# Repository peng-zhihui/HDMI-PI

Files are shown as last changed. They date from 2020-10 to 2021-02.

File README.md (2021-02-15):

> 这是我最近设计的一个HDMI转MIPI模块，可以用于驱动各种手机屏幕当显示器用。

## 有什么用？

大家知道现在的手机屏幕素质非常高，且价格低廉（毕竟有智能手机的普及量撑腰，作为维修配件买的话非常便宜），相比于绝大多数桌面显示器拥有十分无敌的分辨率、像素密度、可视角、色彩还原甚至刷新率。

大家又知道，我对于小巧精致的电子产品有执着的追求，可市面上几乎找不到用手机屏幕做的迷你显示器，所以本项目就是为了解决这个需求。至于迷你HDMI显示器有什么用，电视盒子、单反相机、树莓派之类的开发板都带HDMI接口，**即插即用随身携带的高分屏它不香吗？**

## 硬件原理

目前绝大多数的手机屏幕和小型高分辨率高刷新率屏幕基本都是MIPI接口，相比于RGB、LVDS、SPI等接口MIPI是一个非常强大的高速接口，它分为CSI和DSI两个规格（没错就是树莓派上预留的那个DSI），可以根据带宽需求自由配置lane数，且每个lane传输速率超过1Gbps。

而HDMI是最为常用的视频接口，几乎所有视频输出设备都会带一个HDMI接口。

**因此我们需要的就是一个HDMI转MIPI的硬件模块。**要实现这个目的可以有几种方案，走FPGA或者用ASIC芯片。

用FPGA的方案这里有个老哥开源了：https://hackaday.io/project/364-mipi-dsi-display-shieldhdmi-adapter

他用Spartan-6 FPGA成功驱动了iPhone4的屏幕并接受HDMI的信号输入，感兴趣的可以参考。

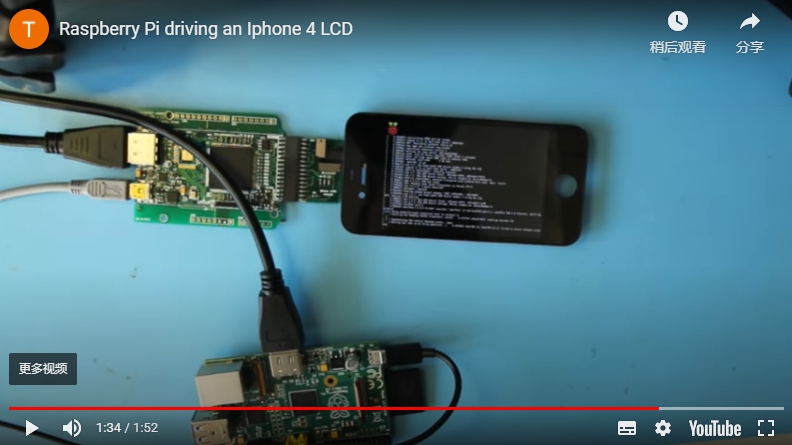
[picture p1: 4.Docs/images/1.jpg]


因为我对FPGA不是很熟，所以我采用ASIC专用IC的方案来设计。

#### 东芝方案

东芝有一款TC358870XBG芯片，支持2x4lane的屏幕驱动，输入源是HDMI，这是目前在AR眼镜中比较流行的一个方案，该芯片非常强大，但是缺点是资料极其稀缺。**我花了很长时间搞到了原厂的datasheet和相关文档，仓库里面都共享出来了。**

根据原厂的评估板我也设计了一个测试模块，电路已经开源在仓库。

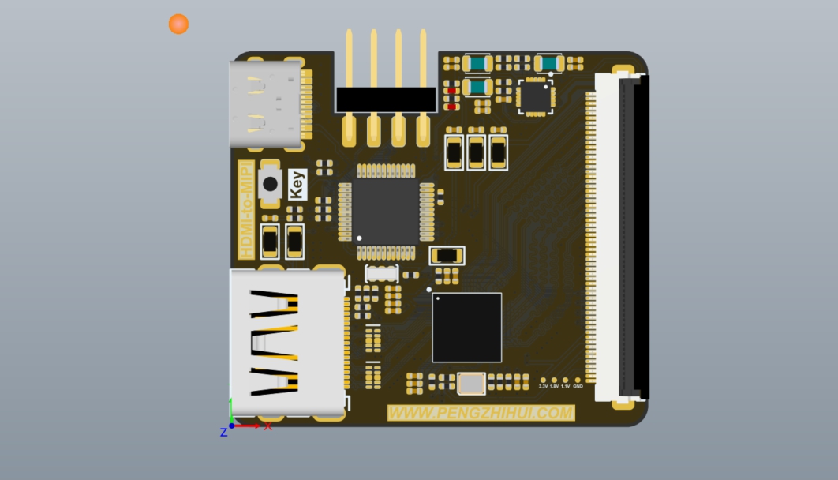
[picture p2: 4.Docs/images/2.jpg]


这个方案的软件我还没有写，感兴趣的同学可以参考文档做后续开发，**也欢迎有进展的同学提交代码到仓库~**

> 目前东芝方案的固件代码已经由[ylj2000](https://github.com/ylj2000)基本实现了，其源码已经整合到本仓库，感谢[ylj2000](https://github.com/ylj2000)同学的开源代码~
>
> 大家可以去他的仓库具体了解：
>
> [ylj2000/HDMI_To_MIPI: A Hdmi to Mipi conversion module based on Toshiba TC358870 (github.com)](https://github.com/ylj2000/HDMI_To_MIPI)

#### 龙讯方案

国产还有一个龙讯方案LT6911，与上面的方案相比龙讯性能上稍弱一些，但是该芯片内置了一个51核的MCU，所以可以直接在片上编程（东芝的需要额外加一个单片机用I2C配置芯片）。

该方案的优点就是成本相对较低，芯片外围电路也更简洁，缺点是，**资料比东芝的还少...**

厂家不开放软硬资料，连datasheet都没有，所以几乎无法个人开发。**但是**，万能的野生钢铁侠通过一些特殊手段，还是跟代理商拿到了一些资料，包括部分源码（核心lib封装好了我拿不到，只有上层API）。但是因为签了NDA保密协议，源码部分我不好分享出来，除了源码其他部分我都开源了，而大家DIY的话也不需要源码，我可以提供预编译的固件供大家下载，所以这个方案适合给直接复制项目的同学参考。

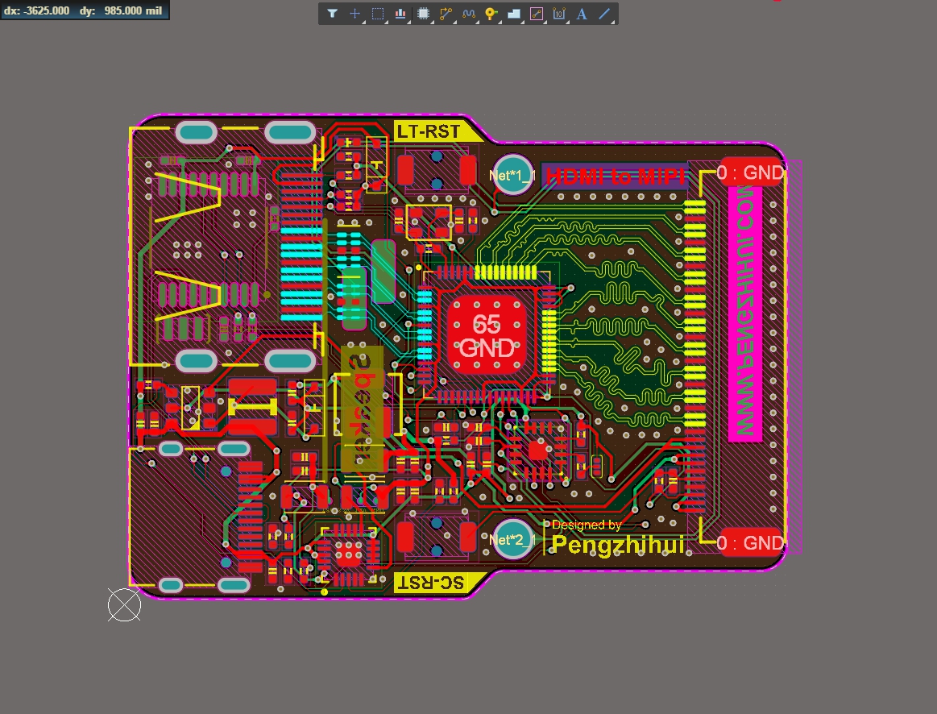
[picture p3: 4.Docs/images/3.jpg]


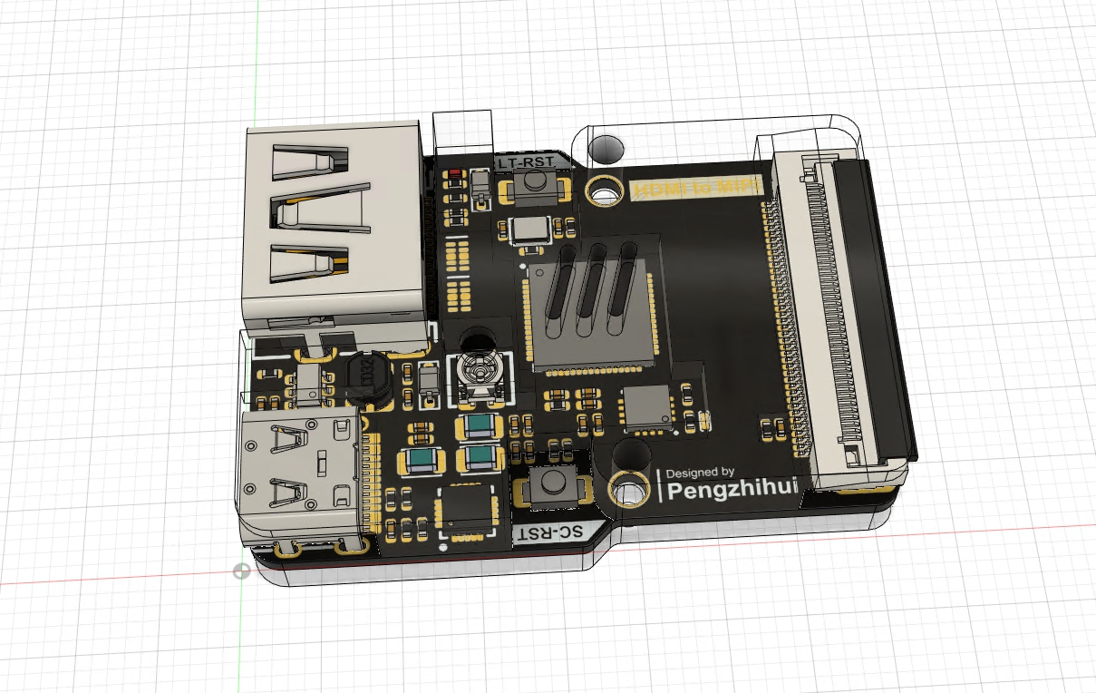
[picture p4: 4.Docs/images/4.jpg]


最终驱动的效果如下，以5.5寸的屏幕为例：

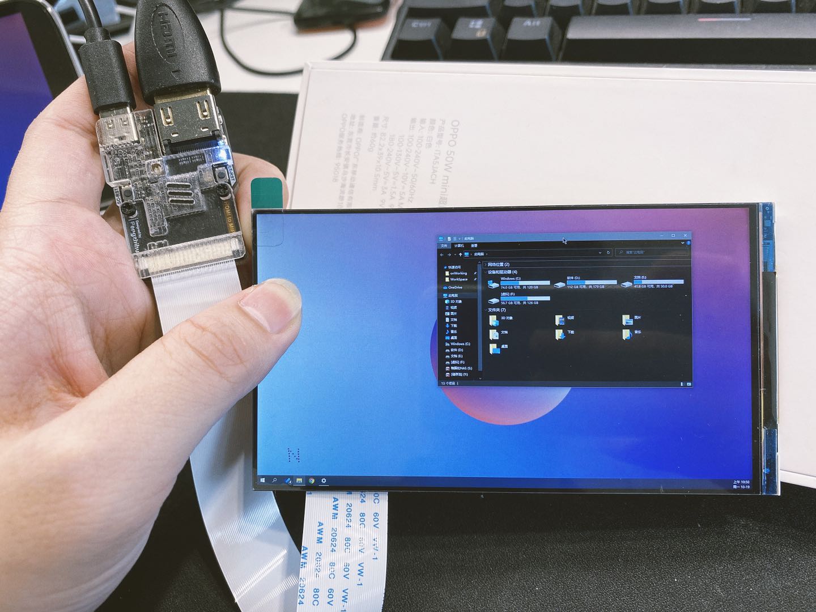
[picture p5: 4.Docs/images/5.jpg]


## 总结

我后面还会继续用这个模块尝试驱动更多屏幕，有开发能力的同学可以在我给出的东芝方案的基础上继续开发，这个方案的自由度会高很多，我后面有空也会继续完成这个方案的:D

#### 找资料和开发不易，记得给仓库点星星哈~~

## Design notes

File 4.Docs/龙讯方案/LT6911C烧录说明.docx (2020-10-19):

1、LT6911x使用IIC去进行烧录，必须使用USB转IIC工具

淘宝上搜索“CH341T模块 USB转12C”，就能找到这个模块。

2、安装好USB转IIC工具及驱动后，在设备管理器里面就有这个设备，驱动可以找淘宝店主提供

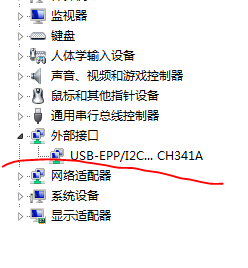
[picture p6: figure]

3、根据IIC总线的”SDA”,”SCL”,”GND”线序连接好开发板与模块，给模块上电（3.3V）

4、打开烧录工具“LT1605_I2C2SPI_V2_100k.exe”（从LT1605_download_tool.rar里面解压出来），选择好烧录码，点击“烧写”，等待烧录成功。

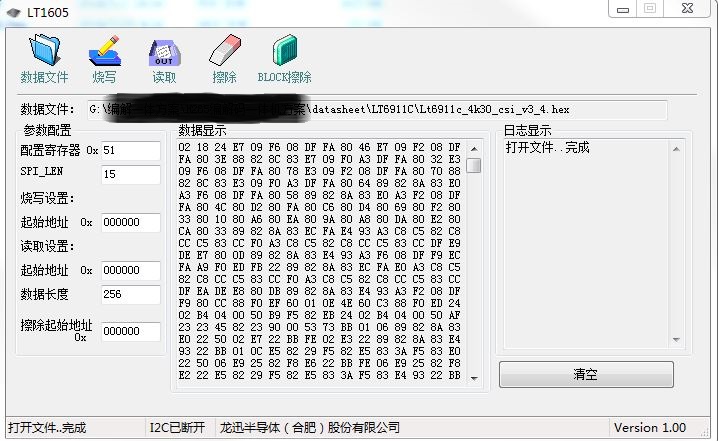
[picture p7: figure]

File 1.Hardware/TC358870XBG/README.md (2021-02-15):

## 文件说明

* MiniDisplay：这是我原版设计电路，硬件已经验证过但是固件代码还没来得及写
* Converter-10.1：和上面的核心板配套的10.1寸屏转接板
* MiniDisplay-ylj2000：这是由[ylj2000](https://github.com/ylj2000)基于我原版硬件方案修改的电路，将转接板改为了排针连接的形式，另外这个方案的固件代码也已经由[ylj2000](https://github.com/ylj2000)实现，目前适配了5.5寸的1080p屏幕
* Converter_5_5：和上面的板子配套的转接板

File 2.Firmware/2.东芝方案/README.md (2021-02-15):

#### By [ylj2000](https://github.com/ylj2000)

# 关于硬件和软件

>这个项目的硬件部分参考了稚晖的原理图，PCB部分由于原版的板厂做出来价格太高，所以进行了重画，是一块核心板加一块转接板的方式。这里两块板之间的连接是用的排针，虽然对这种高速信号来说不太好，但是实际测试是可以使用的。屏幕使用的是稚晖POCKET-LCD开源项目中的那块屏幕，开源链接：https://github.com/peng-zhihui/PocketLCD。
>由于龙迅方案的资料等都不太好弄到，所以这个项目做的是东芝方案，目前已经点亮了这块屏幕，之后也会尽量找时间点亮其他屏幕。由于MIPI屏幕的特性，必须针对每一块屏幕定制驱动。这个项目会开源点亮屏幕的源码，目前还没有写状态切换方面的代码，只能先插上HDMI之后再插上电源才能显示，如果拔下HDMI就需要重新上电。由于原版的原理图中iic接口没加上拉电阻，我这里也没有注意到，所以在调试的时候需要外接iic的上拉。

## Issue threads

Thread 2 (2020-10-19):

有没有考虑出售成品方案呢，新手不会弄啊

fanxinghaoyue0, 2020-10-19:

ice-shimmer, 2020-10-19:
或者能不能教我们怎么用这些资料在淘宝上定做

fanxinghaoyue0, 2020-10-19:
> 或者能不能教我们怎么用这些资料在淘宝上定做

哈哈你这个太伸手党了

ice-shimmer, 2020-10-19:
> > 或者能不能教我们怎么用这些资料在淘宝上定做
>
> 哈哈你这个太伸手党了

啊这。。说的怪不好意思的，但是真的是没有啥基础啊

Leadrive, 2020-10-19:
我也没基础，点个星支持下。

lizhaoguosina, 2020-10-19:
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

先下载下来，然后用AD打开，导出成打板工厂要求的文件在线下单打板就好了。等板子回来然后对应的焊接应该就好了。只是我实在不确定哪家的芯片可以胜任这项任务😂

Professor-Chen, 2020-11-29:
有成品，大家一起拼pocket-lcd   qq群：719019471

willshion, 2020-11-30:
其它屏幕捏？ 小米？？？
做不做 摄像头驱动？？？
为环保 点star

Professor-Chen, 2020-11-30:
其他屏幕没有驱动暂时做不了
不做

------------------&nbsp;原始邮件&nbsp;------------------
发件人:                                                                                                                        "peng-zhihui/HDMI-PI"                                                                                    <notifications@github.com&gt;;
发送时间:&nbsp;2020年12月1日(星期二) 凌晨0:50
收件人:&nbsp;"peng-zhihui/HDMI-PI"<HDMI-PI@noreply.github.com&gt;;
抄送:&nbsp;"1224288756"<1224288756@qq.com&gt;;"Comment"<comment@noreply.github.com&gt;;
主题:&nbsp;Re: [peng-zhihui/HDMI-PI] 有没有考虑出售成品方案呢，新手不会弄啊 (#2)

其它屏幕捏？ 小米？？？
 做不做 摄像头驱动？？？
 为环保 点star

—
You are receiving this because you commented.
Reply to this email directly, view it on GitHub, or unsubscribe.

materliu, 2021-02-24:
同求成品，愿意掏钱买

rcHoper, 2021-02-24:
TB有现货的，300rmb左右

materliu, 2021-02-24:
> TB有现货的，300rmb左右

关键字是啥啊

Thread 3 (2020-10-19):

求屏幕型号

Libunko, 2020-10-19:
README手上拿的那块屏幕是什么型号啊，夏普的吗？

Libunko, 2020-10-20:
[屏库网](https://www.panelook.cn/sizmodlist_cn.php?st=E27&pl=&sizes[]=550&signal_type_category=140&st=E27&by=asc&production_state=-1&best=0) 可以按条件搜索屏幕面板

Closed 2020-10-20.

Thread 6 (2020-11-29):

关于屏幕、DSI和树莓派

nineandthreequarters, 2020-11-29:
> 树莓派有 **_DSI_** +手机屏幕用 **_DSI_**  ==> 树莓派可以直接连手机拆机屏幕进行显示
>- [ ] **这条假设成立吗？**

tansirui, 2020-11-29:
应该不可以直接用，单单接口就得转接。

12101111, 2020-11-29:
https://github.com/anholt/linux/wiki/VC4-display-support
https://github.com/anholt/linux/wiki/Raspberry-Pi-and-other-MIPI-DSI-display-panels
https://www.cnblogs.com/B1ue/p/10334900.html

Closed 2020-11-29.

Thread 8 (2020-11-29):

关于所支持的屏幕分辨率

JYH851, 2020-11-29:
在固件中我看到那个固件的标题中写的是800*1280，我想知道是这个固件只能支持这个分辨率吗

peng-zhihui, 2020-11-29:
不只是分辨率，驱动屏幕的核心是对接屏幕控制器，每一块屏幕都不一样的，需要针对特定屏幕修改固件（虽然同一型号的控制器修改量很小）

发自我的iPhone

------------------ 原始邮件 ------------------
发件人: JYH851 <notifications@github.com&gt;
发送时间: 2020年11月29日 17:29
收件人: peng-zhihui/HDMI-PI <HDMI-PI@noreply.github.com&gt;
抄送: Subscribed <subscribed@noreply.github.com&gt;
主题: 回复：[peng-zhihui/HDMI-PI] 关于所支持的屏幕分辨率 (#8)

在固件中我看到那个固件的标题中写的是800*1280，我想知道是这个固件只能支持这个分辨率吗

—
You are receiving this because you are subscribed to this thread.
Reply to this email directly, view it on GitHub, or unsubscribe.

0x01x0, 2020-11-29:
有个报废iPad屏幕 能不能上？

Closed 2020-11-29.

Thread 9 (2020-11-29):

关于转接板

tansirui, 2020-11-29:
你好，请问一下仓库里是不是没有阿美林5.5寸的转接板？如果自己画的差分线要怎么处理？

hexesdesu, 2020-11-30:
把pocketlcd里面的转接部分抠出来用(￣o￣) . z Z

tansirui, 2020-12-01:
> 把pocketlcd里面的转接部分抠出来用(￣o￣) . z Z

线序不一样的，已经重画了。

binglebai, 2020-12-18:
可以上传分享一下阿美林5.5寸的转接板吗？

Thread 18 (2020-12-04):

Toshiba schematic is missing Resistor values

ktoanlba89, 2020-12-04:
First. Sorry because i using English here.

I'm trying to work with Toshiba solution. But i couldn't find exactly value of R23, R25 and R29.
I am not familiar with electronics to understand all thing here.

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

Could anyone help me here.

Thanks

tansirui, 2020-12-05:
R29

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

Nc means not connected, so R25, R29 can be unwelded. R23 uses 0 ohm resistor to short circuit.

ktoanlba89, 2020-12-05:
I make sense. Thank @tansirui so much

Closed 2020-12-05.

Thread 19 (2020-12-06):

关于type-C接口加入屏幕扩展显示的想法

MarkVickey, 2020-12-06:
想问下大佬，有没有可能实现用type-C来实现屏幕数据的传输，就像淘宝的type-C扩展屏幕一样 扩展手机或电脑的屏幕？这样我觉得可以减少一个HDMI口来增加一个USB-A或Type-C变成一个更实用的充电宝，虽然可能跟大佬一开始的痛点有点背离。。。。。。

smilelc3, 2020-12-18:
TYPE-C走视频的是a/t 模式，需要DP信号，用东芝方案，估计就得再加DP->HDMI芯片，成本可就上去了，而且方案就变成DP->HDMI->MIPI，则有点托大了

a44281071, 2020-12-30:
我在任天堂switch出来之后，一直想用我的安卓平板当显示器用，这个好像给了点出路，厉害了！

summershrimp, 2021-06-16:
龙讯有dp to mipi的方案。。理论上可以做type-c dp-alt的

MuYiIsYang, 2023-05-29:
正有此意，不知老哥有没有方案了

MarkVickey, 2023-06-01:
目前还没有，后面玩3D打印了😂

---原始邮件---
发件人: ***@***.***&gt;
发送时间: 2023年5月30日(周二) 凌晨3:02
收件人: ***@***.***&gt;;
抄送: ***@***.******@***.***&gt;;
主题: Re: [peng-zhihui/HDMI-PI] 关于type-C接口加入屏幕扩展显示的想法 (#19)

正有此意，不知老哥有没有方案了

—
Reply to this email directly, view it on GitHub, or unsubscribe.
You are receiving this because you authored the thread.Message ID: ***@***.***&gt;

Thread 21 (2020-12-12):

固件匹配问题

0Xxiyou, 2020-12-12:
目前提供的固件名称是LT6911C_HDMI2MIPI_4lans_dsi_800x1280.hex，是不是代表该固件只支持屏幕资料里面的”10.1寸MIPI屏800x1280“这款屏幕。

onlinelei, 2021-07-23:
同问，手里有 京东方 TV101WXM-NL3 800(RGB)×1280, WXGA, 150PPI  也是这个尺寸，也可以用这个固件吗

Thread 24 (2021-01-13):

关于我创建的一个技术交流群

kumonohayaku, 2021-01-13:
我创了个技术交流群，欢迎dalao们进来讨论，非拼车群，主要交流如何自己驱动任意液晶屏和驱动板设计开发等等，本人也对如何驱动mipi液晶不太了解，目前正在调试开发中，目标是驱动一个6.8寸1080的屏幕。
群号：879256453

kumonohayaku, 2021-03-11:
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
2021-3-8成功调试成功，感谢各位大佬们，最后驱动程序将整合在https://github.com/ylj2000/HDMI_To_MIPI的项目里。

peng-zhihui, 2021-03-11:
很棒，感谢分享~

Closed 2021-03-11.

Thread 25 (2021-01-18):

可以添加硬件的封装库进来么

zhoaji, 2021-01-18:

peng-zhihui, 2021-01-18:
网上自己搜索“AD导出库文件”

发自我的iPhone

------------------ 原始邮件 ------------------
发件人: Lee <notifications@github.com&gt;
发送时间: 2021年1月18日 11:16
收件人: peng-zhihui/HDMI-PI <HDMI-PI@noreply.github.com&gt;
抄送: Subscribed <subscribed@noreply.github.com&gt;
主题: 回复：[peng-zhihui/HDMI-PI] 可以添加硬件的封装库进来么 (#25)

—
You are receiving this because you are subscribed to this thread.
Reply to this email directly, view it on GitHub, or unsubscribe.

zhoaji, 2021-01-18:
好的&nbsp; 谢谢

------------------&nbsp;原始邮件&nbsp;------------------
发件人: "稚晖"<notifications@github.com&gt;;
发送时间: 2021年1月18日(星期一) 中午11:29
收件人: "peng-zhihui/HDMI-PI"<HDMI-PI@noreply.github.com&gt;;
抄送: "👿小淘气"<357499926@qq.com&gt;; "Author"<author@noreply.github.com&gt;;
主题: Re: [peng-zhihui/HDMI-PI] 可以添加硬件的封装库进来么 (#25)

 网上自己搜索“AD导出库文件”

 发自我的iPhone

 ------------------ 原始邮件 ------------------
 发件人: Lee <notifications@github.com&amp;gt;
 发送时间: 2021年1月18日 11:16
 收件人: peng-zhihui/HDMI-PI <HDMI-PI@noreply.github.com&amp;gt;
 抄送: Subscribed <subscribed@noreply.github.com&amp;gt;
 主题: 回复：[peng-zhihui/HDMI-PI] 可以添加硬件的封装库进来么 (#25)

 —
 You are receiving this because you are subscribed to this thread.
 Reply to this email directly, view it on GitHub, or unsubscribe.
—
You are receiving this because you authored the thread.
Reply to this email directly, view it on GitHub, or unsubscribe.

skq7929, 2021-01-26:
有PCB文件，你可以自己生成PCB的封装库自己用呗

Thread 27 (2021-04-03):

关于DSI-MIPI的方案

MarioLee, 2021-04-03:
在研究树莓派的屏幕解决方案的时候，发现了有MIPI-DSI的方案，但是苦于找不到相关的开发资料
当前树莓派可以用大佬的HDMI接MIPI解决方案来实现屏幕，但触控模块的信号无法通过HDMI传输
请问大佬对触控模块通过HDMI－MIPI或者MIPI-DSI有研究吗：）

summershrimp, 2021-06-16:
触控都是走usb/i2c/spi之类的总线和，和mipi本身没关系把

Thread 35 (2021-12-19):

有没有LT6911C的数据手册？可否发下？

Xlop, 2021-12-19:
我这边又个自己拆机下来的屏，东西网上找不到任何相关信息，但是找到类似的，需要一个-2.5V和一个+2.5V的电压，我像知道芯片引脚是否有输出-2.5V的电压，需找下手册，有的麻烦私发下。

vayyi, 2022-02-09:
found only for lt6911uxc in HDMI2MIPI on gitee.com
and registers on Lontium_lt6911uxc here on github
cant find any on 6911c, would be nice to have more lcds available for this

peng-zhihui, 2022-02-09:
上传了，在Doc里面

Xlop, 2023-02-26:
完成项目了，非常感谢。

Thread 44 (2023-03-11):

4K 60Hz 方案

kwankiu, 2023-03-11:
LT6911UXC支持4K 60Hz，footprint 和 pin 是相同的，有大佬能确认一下这个芯片是否可以直接用还是需要修改PCB文件？

有大佬能帮忙编译一下夏普[LS029B3SX06](https://www.panelook.com/LS029B3SX06_Sharp_2.9_LCM_parameter_41940.html) 5.5寸4K液晶显示器的固件吗？

The LT6911UXC support 4K 60Hz, the footprint is the same, can anyone confirm that this chip can be used or does it need any changes to the PCB?

Can anybody help compiling a firmware for the Sharp [LS029B3SX06](https://www.panelook.com/LS029B3SX06_Sharp_2.9_LCM_parameter_41940.html) 5.5-inch 4K LCD Display?

Datasheets :
[5.5寸4K屏.pdf](https://github.com/peng-zhihui/HDMI-PI/files/10948429/5.5.4K.pdf)
[LT6911UXC.pdf](https://github.com/peng-zhihui/HDMI-PI/files/10948430/LT6911UXC.pdf)
[LT6911UXC_HDMI_TO_MIPI+LVDS_HV2_1.pdf](https://github.com/peng-zhihui/HDMI-PI/files/10948432/LT6911UXC_HDMI_TO_MIPI%2BLVDS_HV2_1.pdf)

ASTACLE, 2025-02-05:
所以大哥这个方案成功了吗

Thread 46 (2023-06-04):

mipi转hdmi

luckey-tree, 2023-06-04:
既然能实现hdmi输入mipi输出，那么是否可以反向操作，让手机主板mipi信号输出到hdmi，这样就可以把废旧手机完全改装成一台linux电脑。（电视盒子原理）

LeviaCh, 2023-07-07:
有點脫褲子放屁的感覺？有不少比較新的手機都支持HDMI輸出啊，加一個USB-C dock就可以了

dingxy1996, 2024-02-21:
> 有點脫褲子放屁的感覺？有不少比較新的手機都支持HDMI輸出啊，加一個USB-C dock就可以了

不支持MHL和USB-C DP输出的老设备还是很多的（更别说很多新设备也不支持），与其作为垃圾处理，如果可以实现MDPI to HDMI，做一个机顶盒还是很不错的。

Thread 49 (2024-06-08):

请问lt6911c只有编译好的固件吗？没有源码吗？

Chen-ce, 2024-06-08:
之前遗留的一个板子上面刚好是lt6911c，61pin接口，淘了一个2k屏幕，发现最多只支持30hz的刷新率，找遍全网都没有这个6911c的资料

Chen-ce, 2024-06-08:
![Uploading 微信图片_20240608135959.jpg…]()

Chen-ce, 2024-06-08:
![Uploading 微信图片_20240608135959.jpg…]()

Beanv587, 2024-07-16:
想要源码 某宝上1200有

colorhacker, 2025-09-20:
闲鱼 固件生成器 很方便

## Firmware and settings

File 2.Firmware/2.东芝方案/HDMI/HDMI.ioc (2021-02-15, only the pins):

Mcu.UserName=STM32F103C8Tx
PA13.Signal=SYS_JTMS-SWDIO
PA14.Signal=SYS_JTCK-SWCLK
PB10.Signal=GPIO_Output
PB6.Signal=I2C1_SCL
PB7.Signal=I2C1_SDA
PB8.Signal=GPIO_Input
PB9.Signal=GPIO_Output
PD0-OSC_IN.Signal=RCC_OSC_IN
PD1-OSC_OUT.Signal=RCC_OSC_OUT

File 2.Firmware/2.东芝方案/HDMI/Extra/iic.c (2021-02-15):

#include "iic.h"
#include "panel.h"

uint8_t data[16];
HAL_StatusTypeDef ylj;

void i2cReadBytes(unsigned short DevID,unsigned short Addr,unsigned char *Pbuf,unsigned short Num)
{
	if((ylj=HAL_I2C_Mem_Read(&hi2c1,DevID,Addr,sizeof(Addr),Pbuf,Num,0xff))==HAL_BUSY)
	{
		HAL_I2C_DeInit(&hi2c1);//iic error,deinit
		HAL_I2C_Init(&hi2c1); 
		
		i2cReadBytes(DevID,Addr,Pbuf,Num);
	}
}

void i2cWriteBytes(unsigned short DevID,unsigned short Addr,unsigned char *Dat,unsigned short Num)
{
	if((ylj=HAL_I2C_Mem_Write(&hi2c1,DevID,Addr,sizeof(Addr),Dat,Num,0xff))==HAL_BUSY)
	{
		HAL_I2C_DeInit(&hi2c1);//iic error,deinit
		HAL_I2C_Init(&hi2c1); 
		
		i2cWriteBytes(DevID,Addr,Dat,Num);
	}
}

void i2c1_uh2d_write8(uint16_t add,uint8_t data)
{
	i2cWriteBytes(0x1e,add,&data,1);
}

void i2c1_uh2d_write16(uint16_t add,uint16_t data)
{
	uint8_t buf[2];
	buf[0]=data;
	buf[1]=(data>>8);
	i2cWriteBytes(0x1e,add,buf,2);
}

void i2c1_uh2d_write32(uint16_t add,uint32_t data)
{
	uint8_t buf[4];
	buf[0]=data;
	buf[1]=(data>>8);
	buf[2]=(data>>16);
	buf[3]=(data>>24);
	i2cWriteBytes(0x1e,add,buf,4);
}

void Panel_Init(void)
{
	uint16_t i,end1=sizeof(panel_init_data1),end2=sizeof(panel_init_data2),temp;
	
	for(i=0;i<end1;i+=2)
	{
		temp=panel_init_data1[i+1];
		temp=temp<<8;
		temp=temp|panel_init_data1[i];
		i2c1_uh2d_write16(0x0504,0x0015);		
		i2c1_uh2d_write16(0x0504,temp);
		HAL_Delay(1);
	}
	HAL_Delay(150);
	
	for(i=0;i<end2;i+=2)
	{
		temp=panel_init_data2[i+1];
		temp=temp<<8;
		temp=temp|panel_init_data2[i];
		i2c1_uh2d_write16(0x0504,0x0015);		
		i2c1_uh2d_write16(0x0504,temp);
		HAL_Delay(1);
	}
	
	//exit sleep
	i2c1_uh2d_write16(0x0504,0x0005); // DCSCMD_Q				
	i2c1_uh2d_write16(0x0504,0x0011); // DCSCMD_Q				
	HAL_Delay(150);
}

void HDMI_Startup(void)
{
	// Software Reset				
	i2c1_uh2d_write16(0x0004,0x0004); // ConfCtl0				
	i2c1_uh2d_write16(0x0002,0x3F01); // SysCtl				
	i2c1_uh2d_write16(0x0002,0x0080); // SysCtl				
	i2c1_uh2d_write16(0x0006,0x0008); // ConfCtl1				
	// DSI-TX0 Transition Timing				
	i2c1_uh2d_write32(0x0108,0x00000001); // DSI_TX_CLKEN				
	i2c1_uh2d_write32(0x010C,0x00000001); // DSI_TX_CLKSEL				
	i2c1_uh2d_write32(0x02A0,0x00000001); // MIPI_PLL_CONTROL				
	i2c1_uh2d_write32(0x02AC,0x000090CF); // MIPI_PLL_CNF				
	HAL_Delay(1);			
	i2c1_uh2d_write32(0x02A0,0x00000003); // MIPI_PLL_CONTROL				
	i2c1_uh2d_write32(0x0118,0x00000014); // LANE_ENABLE				
	i2c1_uh2d_write32(0x0120,0x00001770); // LINE_INIT_COUNT				
	i2c1_uh2d_write32(0x0124,0x00000000); // HSTX_TO_COUNT				
	i2c1_uh2d_write32(0x0128,0x00000101); // FUNC_ENABLE				
	i2c1_uh2d_write32(0x0130,0x00010000); // DSI_TATO_COUNT				
	i2c1_uh2d_write32(0x0134,0x00005000); // DSI_PRESP_BTA_COUNT				
	i2c1_uh2d_write32(0x0138,0x00010000); // DSI_PRESP_LPR_COUNT				
	i2c1_uh2d_write32(0x013C,0x00010000); // DSI_PRESP_LPW_COUNT				
	i2c1_uh2d_write32(0x0140,0x00010000); // DSI_PRESP_HSR_COUNT				
	i2c1_uh2d_write32(0x0144,0x00010000); // DSI_PRESP_HSW_COUNT				
	i2c1_uh2d_write32(0x0148,0x00001000); // DSI_PR_TO_COUNT				
	i2c1_uh2d_write32(0x014C,0x00010000); // DSI_LRX-H_TO_COUNT				
	i2c1_uh2d_write32(0x0150,0x00000160); // FUNC_MODE				
	i2c1_uh2d_write32(0x0154,0x00000001); // DSI_RX_VC_ENABLE				
	i2c1_uh2d_write32(0x0158,0x000000C8); // IND_TO_COUNT				
	i2c1_uh2d_write32(0x0168,0x0000002A); // DSI_HSYNC_STOP_COUNT				
	i2c1_uh2d_write32(0x0170,0x0000040D); // APF_VDELAYCNT				
	i2c1_uh2d_write32(0x017C,0x00000081); // DSI_TX_MODE				
	i2c1_uh2d_write32(0x018C,0x00000001); // DSI_HSYNC_WIDTH				
	i2c1_uh2d_write32(0x0190,0x00000104); // DSI_HBPR				
	i2c1_uh2d_write32(0x01A4,0x00000000); // DSI_RX_STATE_INT_MASK				
	i2c1_uh2d_write32(0x01C0,0x00000015); // DSI_LPRX_THRESH_COUNT				
	i2c1_uh2d_write32(0x0214,0x00000000); // APP_SIDE_ERR_INT_MASK				
	i2c1_uh2d_write32(0x021C,0x00000080); // DSI_RX_ERR_INT_MASK				
	i2c1_uh2d_write32(0x0224,0x00000000); // DSI_LPTX_INT_MASK				
	i2c1_uh2d_write32(0x0254,0x00000006); // LPTXTIMECNT				
	i2c1_uh2d_write32(0x0258,0x00240204); // TCLK_HEADERCNT				
	i2c1_uh2d_write32(0x025C,0x000D0008); // TCLK_TRAILCNT				
	i2c1_uh2d_write32(0x0260,0x00140006); // THS_HEADERCNT				
	i2c1_uh2d_write32(0x0264,0x00004268); // TWAKEUPCNT				
	i2c1_uh2d_write32(0x0268,0x0000000F); // TCLK_POSTCNT				
	i2c1_uh2d_write32(0x026C,0x000D0008); // THS_TRAILCNT				
	i2c1_uh2d_write32(0x0270,0x00000020); // HSTXVREGCNT				
	i2c1_uh2d_write32(0x0274,0x0000001F); // HSTXVREGEN				
	i2c1_uh2d_write32(0x0278,0x00060005); // BTA_COUNT				
	i2c1_uh2d_write32(0x027C,0x00000002); // DPHY_TX ADJUST				
	i2c1_uh2d_write32(0x011C,0x00000001); // DSITX_START				
	// DSI-TX1 Transition Timing				
	i2c1_uh2d_write32(0x0308,0x00000001); // DSI_TX_CLKEN				
	i2c1_uh2d_write32(0x030C,0x00000001); // DSI_TX_CLKSEL				
	i2c1_uh2d_write32(0x04A0,0x00000001); // MIPI_PLL_CONTROL				
	i2c1_uh2d_write32(0x04AC,0x000090CF); // MIPI_PLL_CNF				
	HAL_Delay(1);				
	i2c1_uh2d_write32(0x04A0,0x00000003); // MIPI_PLL_CONTROL				
	i2c1_uh2d_write32(0x0318,0x00000014); // LANE_ENABLE				
	i2c1_uh2d_write32(0x0320,0x00001770); // LINE_INIT_COUNT				
	i2c1_uh2d_write32(0x0324,0x00000000); // HSTX_TO_COUNT				
	i2c1_uh2d_write32(0x0328,0x00000101); // FUNC_ENABLE				
	i2c1_uh2d_write32(0x0330,0x00010000); // DSI_TATO_COUNT				
	i2c1_uh2d_write32(0x0334,0x00005000); // DSI_PRESP_BTA_COUNT				
	i2c1_uh2d_write32(0x0338,0x00010000); // DSI_PRESP_LPR_COUNT				
	i2c1_uh2d_write32(0x033C,0x00010000); // DSI_PRESP_LPW_COUNT				
	i2c1_uh2d_write32(0x0340,0x00010000); // DSI_PRESP_HSR_COUNT				
	i2c1_uh2d_write32(0x0344,0x00010000); // DSI_PRESP_HSW_COUNT				
	i2c1_uh2d_write32(0x0348,0x00001000); // DSI_PR_TO_COUNT				
	i2c1_uh2d_write32(0x034C,0x00010000); // DSI_LRX-H_TO_COUNT				
	i2c1_uh2d_write32(0x0350,0x00000160); // FUNC_MODE				
	i2c1_uh2d_write32(0x0354,0x00000001); // DSI_RX_VC_ENABLE				
	i2c1_uh2d_write32(0x0358,0x000000C8); // IND_TO_COUNT				
	i2c1_uh2d_write32(0x0368,0x0000002A); // DSI_HSYNC_STOP_COUNT				
	i2c1_uh2d_write32(0x0370,0x0000040D); // APF_VDELAYCNT				
	i2c1_uh2d_write32(0x037C,0x00000081); // DSI_TX_MODE				
	i2c1_uh2d_write32(0x038C,0x00000001); // DSI_HSYNC_WIDTH				
	i2c1_uh2d_write32(0x0390,0x00000104); // DSI_HBPR				
	i2c1_uh2d_write32(0x03A4,0x00000000); // DSI_RX_STATE_INT_MASK				
	i2c1_uh2d_write32(0x03C0,0x00000015); // DSI_LPRX_THRESH_COUNT				
	i2c1_uh2d_write32(0x0414,0x00000000); // APP_SIDE_ERR_INT_MASK				
	i2c1_uh2d_write32(0x041C,0x00000080); // DSI_RX_ERR_INT_MASK				
	i2c1_uh2d_write32(0x0424,0x00000000); // DSI_LPTX_INT_MASK				
	i2c1_uh2d_write32(0x0454,0x00000006); // LPTXTIMECNT				
	i2c1_uh2d_write32(0x0458,0x00240204); // TCLK_HEADERCNT				
	i2c1_uh2d_write32(0x045C,0x000D0008); // TCLK_TRAILCNT				
	i2c1_uh2d_write32(0x0460,0x00140006); // THS_HEADERCNT				
	i2c1_uh2d_write32(0x0464,0x00004268); // TWAKEUPCNT				
	i2c1_uh2d_write32(0x0468,0x0000000F); // TCLK_POSTCNT				
	i2c1_uh2d_write32(0x046C,0x000D0008); // THS_TRAILCNT
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

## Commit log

2020-10-19 Init repo.
    [Audio.SchDoc, Connector.SchDoc, Converter.PcbDoc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]
2020-10-19 Add README.md
    [Converter.PcbDoc, Converter.PrjPCB, Main.SchDoc]
2021-02-15 [Hw] Add ylj2000 version TC358870XBG-base hardware.
    [0.PcbDoc, 0.SchDoc, Connector.SchDoc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]
